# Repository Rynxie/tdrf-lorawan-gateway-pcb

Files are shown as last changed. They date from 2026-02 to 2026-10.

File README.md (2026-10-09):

# Open-Source Linux-Based LoRaWAN Gateway

A custom-designed, open-source **LoRaWAN gateway PCB** powered by the **Allwinner V3s ARM Cortex-A7 processor** and the **Semtech SX1302 LoRa concentrator**.

The gateway combines custom hardware with an embedded Linux software stack built using Buildroot, providing a flexible platform for LoRaWAN communication and IoT applications.

## Hardware Prototypes

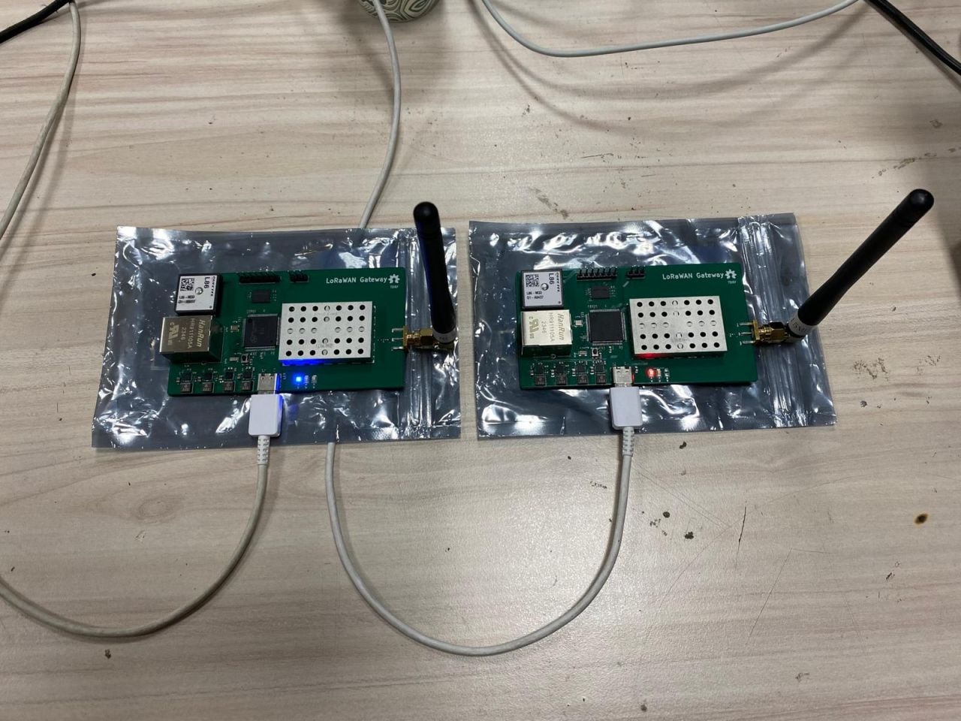
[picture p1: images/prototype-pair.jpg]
Two assembled LoRaWAN gateway prototypes


Two assembled and tested LoRaWAN gateway prototypes.

| Assembled Gateway | PCB Component Layout |
|---|---|
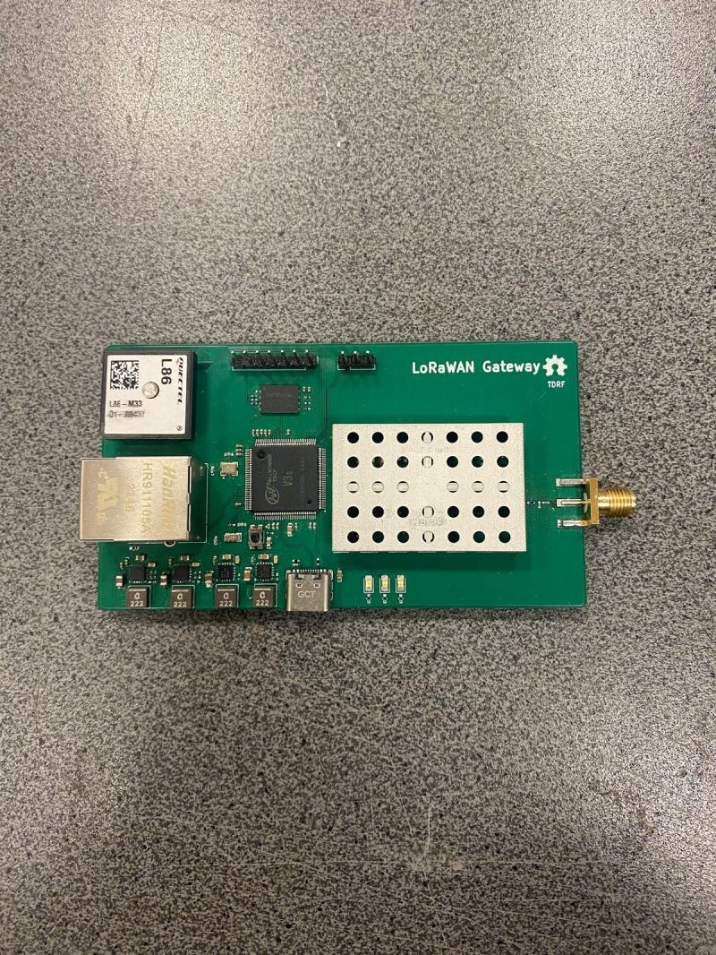
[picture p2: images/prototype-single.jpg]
Gateway prototype
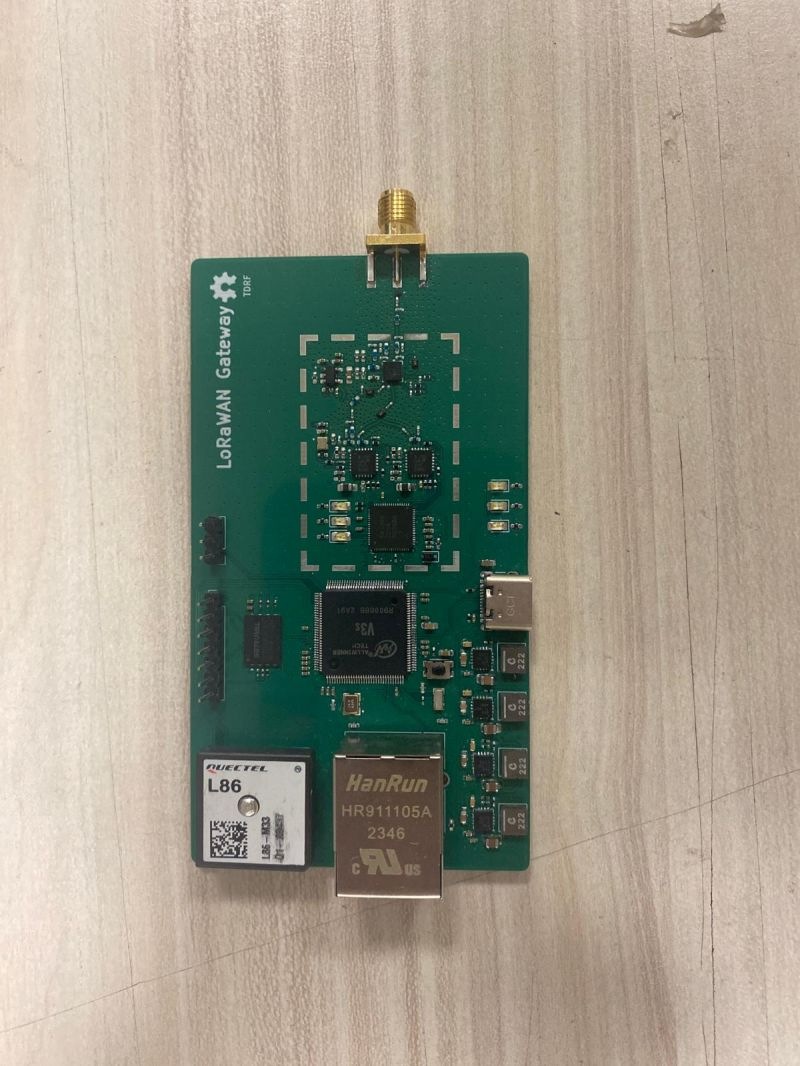
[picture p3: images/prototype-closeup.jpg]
Gateway PCB
|  |  |

## Project Overview

This project focuses on designing and developing a standalone Linux-based LoRaWAN gateway, including both custom PCB hardware and embedded Linux firmware.

The gateway was developed under the **TÜBİTAK 2209-A Undergraduate Research Projects Support Program** and subsequently integrated into the **LoRa-Based Low-Power Tracking System for Critical Cargo**, supported by the **Turkish Aerospace Industries LIFT UP Graduation Project Support Program**.

## Hardware

The hardware was designed in **KiCad**, integrating the processing unit, LoRa concentrator, RF transceivers, and peripheral interfaces on a custom PCB.

### Main Components

| Component | Description |
|---|---|
| Allwinner V3s | ARM Cortex-A7 MPU with integrated 64 MB DDR2 RAM |
| Semtech SX1302 | LoRa Core digital baseband concentrator |
| Semtech SX1250 | LoRa RF transceivers |
| Ethernet | Wired network connectivity |
| Quectel L86 | GNSS module |
| USB Type-C | USB interface |
| Custom PCB | Integrated gateway hardware platform |

## Embedded Linux Software

The gateway runs a customized embedded Linux distribution generated using **Buildroot**.

The software environment includes:

- **Linux Kernel:** Customized for the Allwinner V3s hardware platform
- **BusyBox:** Lightweight userspace utilities
- **Semtech UDP Packet Forwarder:** Forwarding LoRa packets to a network server
- **ChirpStack:** LoRaWAN Network Server integration

### System Architecture

```text
        LoRaWAN End Devices
                 |
                 | LoRa RF
                 v
       +-------------------+
       | Semtech SX1250    |
       | RF Transceivers   |
       +---------+---------+
                 |
                 v
       +-------------------+
       | Semtech SX1302    |
       | LoRa Concentrator |
       +---------+---------+
                 |
                 | SPI
                 v
       +-------------------+
       | Allwinner V3s     |
       | Embedded Linux    |
       | Buildroot         |
       | Packet Forwarder  |
       +---------+---------+
                 |
                 | Ethernet
                 v
       +-------------------+
       | ChirpStack        |
       | LoRaWAN Network   |
       | Server            |
       +-------------------+
```

## Testing and Validation

Two final hardware prototypes were manufactured, assembled, and tested.

The gateway was integrated into a LoRa-based low-power tracking system for critical cargo, providing a practical environment for evaluating the custom hardware and embedded Linux software.

We reached up to **1 km** distance in a urban area and looking for ways to increase the range

## Repository Contents

This repository focuses on the **hardware design** of the LoRaWAN gateway.

It contains the KiCad project and associated hardware design resources, including:

- PCB schematic
- PCB layout
- Component symbols and footprints
- Manufacturing and production files

## Project Team

- **Tunahan Kaya** — Embedded Linux and software development
- **Dilara Tatar** — Hardware development
- **Dr. Yalçın Albayrak** — Academic advisor

## Acknowledgments

This project was supported by the **TÜBİTAK 2209-A Undergraduate Research Projects Support Program**.

The gateway was also integrated and tested within a project supported by the **TUSAŞ LIFT UP Graduation Project Support Program**.

Special thanks to the project team and our academic advisor for their contributions and support throughout the development process.

## References

- [GitHub Repository](https://github.com/Rynxie/tdrf-lorawan-gateway-pcb)
- [Original LinkedIn Post](https://lnkd.in/p/d-5i6TTB)

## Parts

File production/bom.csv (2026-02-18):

Designator | Footprint | Quantity | Value | LCSC Part #
C1, C10, C104, C105, C107, C109, C110, C112, C113, C114, C14, C15, C16, C17, C2, C21, C22, C23, C24, C25, C26, C27, C28, C29, C3, C30, C32, C34, C35, C37, C4, C40, C41, C42, C44, C45, C46, C5, C6, C7, C8, C9 | 0201 | 42 | 100nF
C100, C38, C39 | 0201 | 3 | 10pF
C101 | 0201 | 1 | 1.3pF
C102, C98 | 0402 | 2 | 27
C103, C106, C108, C111, C18, C19, C75, C82 | 0402 | 8 | 1uF
C11, C12 | 0402 | 2 | 470nF
C115, C31, C33, C61, C62, C71, C72 | 0402 | 7 | 100nF
C116, C117, C88 | 0201 | 3 | 100n
C13, C20, C36, C43, C47, C59, C60, C69, C70 | 0603 | 9 | 10uF
C48 | 0402 | 1 | 47nF
C49 | 0201 | 1 | 47pF
C50 | 0603 | 1 | 2.2u
C51, C78, C80 | 0201 | 3 | 3.3pF
C52 | 0201 | 1 | 5.6pF
C53, C54, C56, C57 | 0201 | 4 | 3.6pF
C55 | 0201 | 1 | 39pF
C58 | 0201 | 1 | 2.2pF
C63, C64, C73, C74 | 0402 | 4 | 3.3nF
C65, C66, C76, C85, C86, C87 | 0201 | 6 | 56pF
C67, C68, C81, C83 | 0805 | 4 | 22uF
C77 | 0201 | 1 | 2.7pF
C79 | 0201 | 1 | 1.5pF
C84 | 0603 | 1 | 1u
C89 | 0603 | 1 | 4.7uF
C90 | 0402 | 1 | 10nF
C91, C95 | 0402 | 2 | 18
C92 | 0402 | 1 | 1nF
C93, C96 | 0402 | 2 | 100n
C94, C97 | 0402 | 2 | 100pF
C99 | 0201 | 1 | DNP
D1, D2, D3, D4, D5, D6 | 0805 | 6 | LED
D7 | D_SOD-323F | 1 | BAT54J
FB1 | 0402 | 1 | BLM15PG100SN1D
FL1, FL2, FL3 | B39871B4377P810 | 3 | B39871B4377P810
IC1, IC2 | QFN50P400X400X100-25N-D | 2 | SX1250IMLTRT
IC4 | QFN35P700X700X80-69N-D | 1 | SX1302IMLTRT
J1 | TE_CONSMA020.062-G | 1 | Conn_Coaxial
J2 | PinHeader_1x03_P2.54mm_Vertical | 1 | Conn_01x03_Pin
J3 | RJ45_Hanrun_HR911105A_Horizontal | 1 | RJ45_Hanrun_HR911105A_Horizontal
J5 | USB_C_Receptacle_GCT_USB4105-xx-A_16P_TopMnt_Horizontal | 1 | USB_C_Receptacle_USB2.0_16P
J6 | PinHeader_1x07_P2.54mm_Vertical | 1 | Conn_01x07_Pin
L1, L2, R13 | 0402 | 3 | NC
L10, L11, L13, L14 | L_Coilcraft_XAL4020-XXX | 4 | 2.2uH
L12, L15 | 0402 | 2 | 5.6nH
L16 | 0402 | 1 | 1.2nH
L17 | 1206 | 1 | 600Z
L18 | 0402 | 1 | 6.8nH
L19 | 0402 | 1 | 3nH
L20 | 0402 | 1 | 7.5nH
L3, L4 | 0805 | 2 | 15uH
L5 | 0402 | 1 | 47nH
L6, L9 | 0402 | 2 | 4.7nH
L7, L8 | 0402 | 2 | 12nH
R1, R2, R3 | 0402 | 3 | 0R
R10, R16, R9 | 0201 | 3 | 100kR
R11 | 0201 | 1 | 75kR
R12 | 0201 | 1 | 150kR
R14 | 0402 | 1 | 100kR
R15 | 0201 | 1 | 100k
R17 | 0201 | 1 | 80.6kR
R18 | 0201 | 1 | 220kR
R19, R20, R21 | 0201 | 3 | 1kR
R22 | 0201 | 1 | 47k
R23, R24 | 0201 | 2 | 2k
R25, R26, R27, R28, R32, R35, R36, R38 | 0402 | 8 | 1k
R29 | 0201 | 1 | 10M
R30, R31, R33, R34 | 0201 | 4 | 50
R37, R39, R62, R63, R64 | 0201 | 5 | 10K
R4, R5 | 0201 | 2 | 220R
R40 | 0402 | 1 | 10R
R41, R42, R44 | 0201 | 3 | 47kR
R43 | 0201 | 1 | 100R
R45, R46 | 0201 | 2 | 5.1kR
R47, R48, R49, R50, R51, R52, R53, R54, R55, R56, R57, R58 | 0201 | 12 | 0R
R59, R60 | 0201 | 2 | 4.7kR
R6 | 0201 | 1 | 240
R61 | 0201 | 1 | 22R
R7, R8 | 0201 | 2 | 12k
SW1 | KMR7_CNK | 1 | KMR731NG LFS
U1 | QFP40P1600X1600X160-129N | 1 | AllwinnerV3S
U10 | shield | 1 | BMI-S-205-C
U11 | SDTRUVAL_SDG02GWSIGA-CSNP2 | 1 | SDG02GWSIGA-CSNP2
U2 | XCVR_L86M33 | 1 | L86M33
U3 | VQFN-16-1EP_3x3mm_P0.5mm_EP1.68x1.68mm_ThermalVias | 1 | TPS62132
U4, U7 | VQFN-16-1EP_3x3mm_P0.5mm_EP1.68x1.68mm_ThermalVias | 2 | TPS62130
U5 | Texas_DPY0002A_0.6x1mm_P0.65mm | 1 | ESD701DPYR
U6 | VQFN-16-1EP_3x3mm_P0.5mm_EP1.68x1.68mm_ThermalVias | 1 | TPS62131
U8 | SOT95P280X145-5N | 1 | TPS7A2033PDBVR
U9 | MCM16_3X3X0P75_SKY | 1 | SKY66420-11
Y1 | OSC_TX21-M010S-32.000-X-R | 1 | TX21-M010S-32.000-X-R
Y2 | ABS07 | 1 | ABS07-32.768KHZ-7-T
Y3 | ABM810000MHZ12D2W | 1 | ABM8-24.000MHZ-B2-T

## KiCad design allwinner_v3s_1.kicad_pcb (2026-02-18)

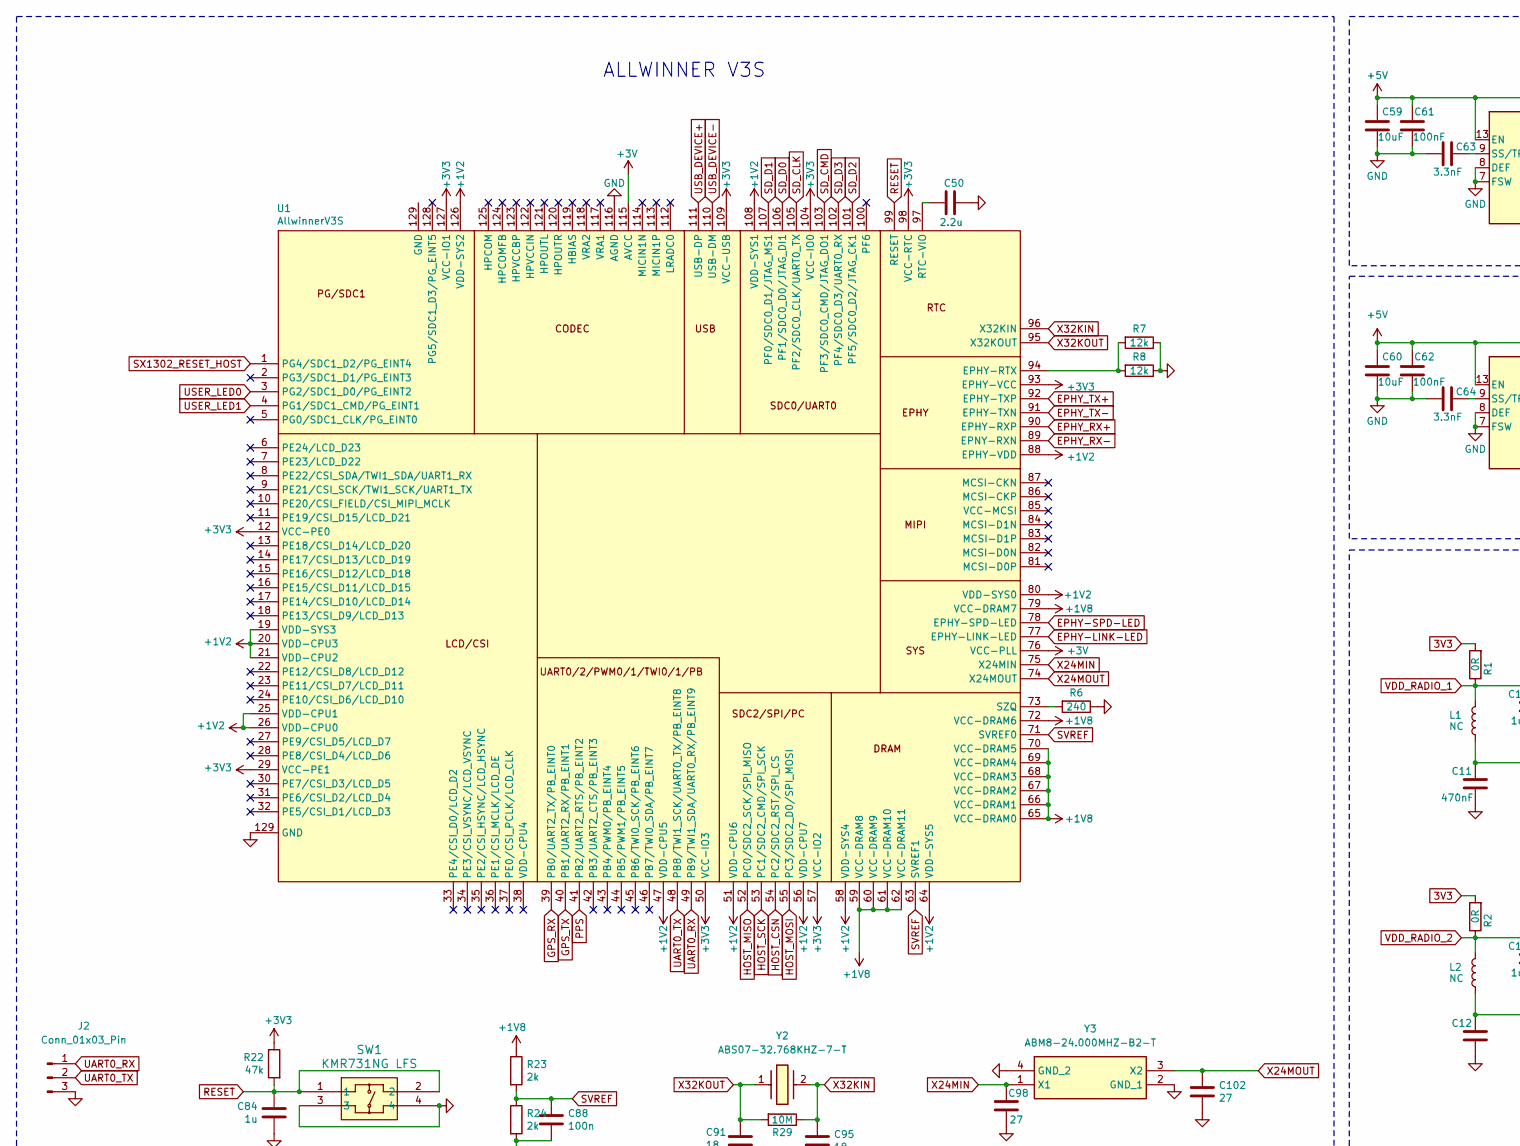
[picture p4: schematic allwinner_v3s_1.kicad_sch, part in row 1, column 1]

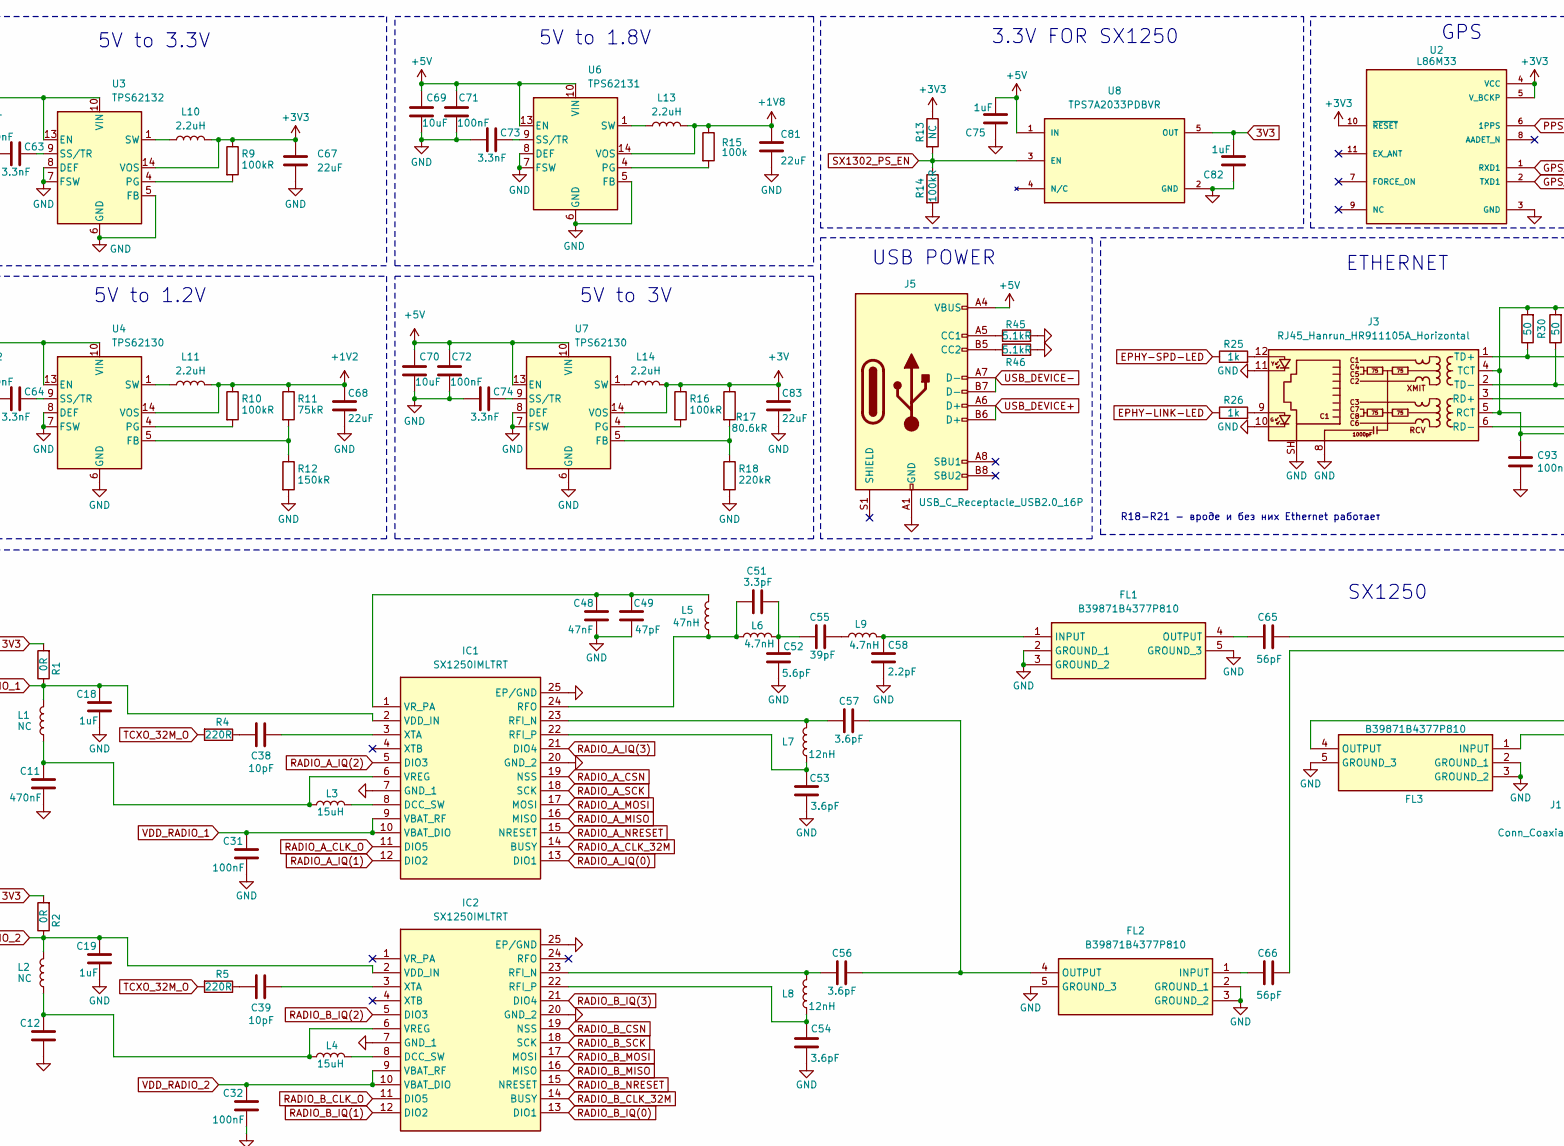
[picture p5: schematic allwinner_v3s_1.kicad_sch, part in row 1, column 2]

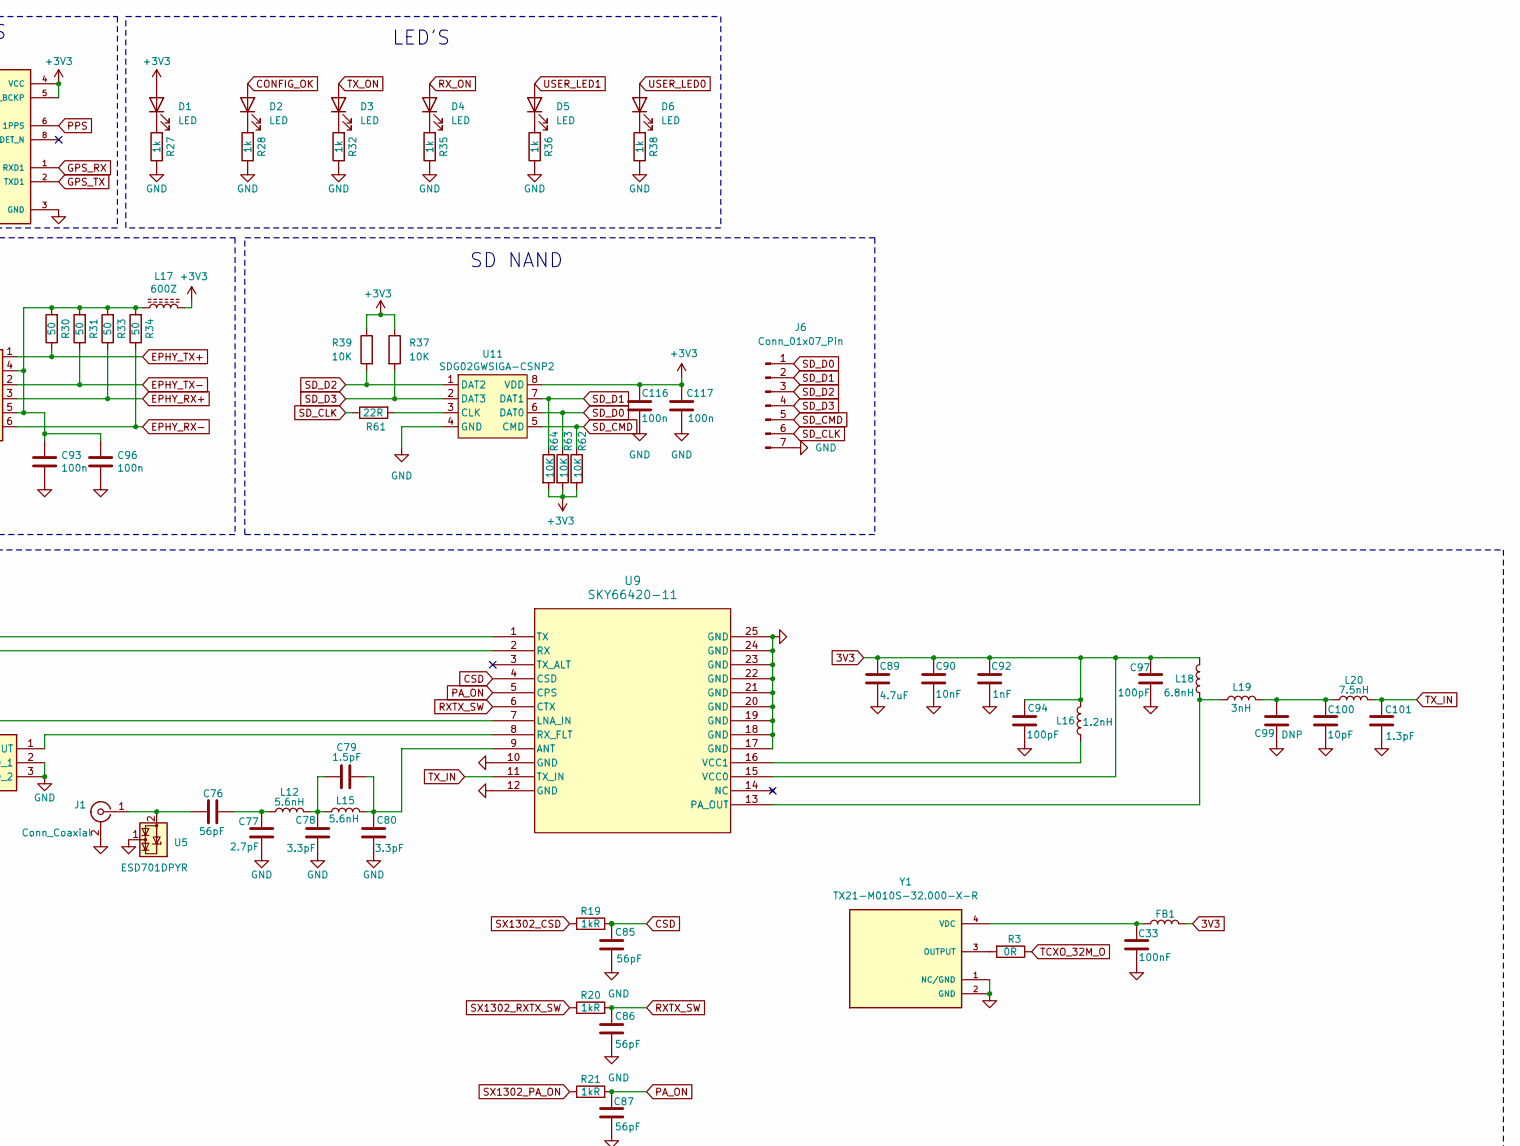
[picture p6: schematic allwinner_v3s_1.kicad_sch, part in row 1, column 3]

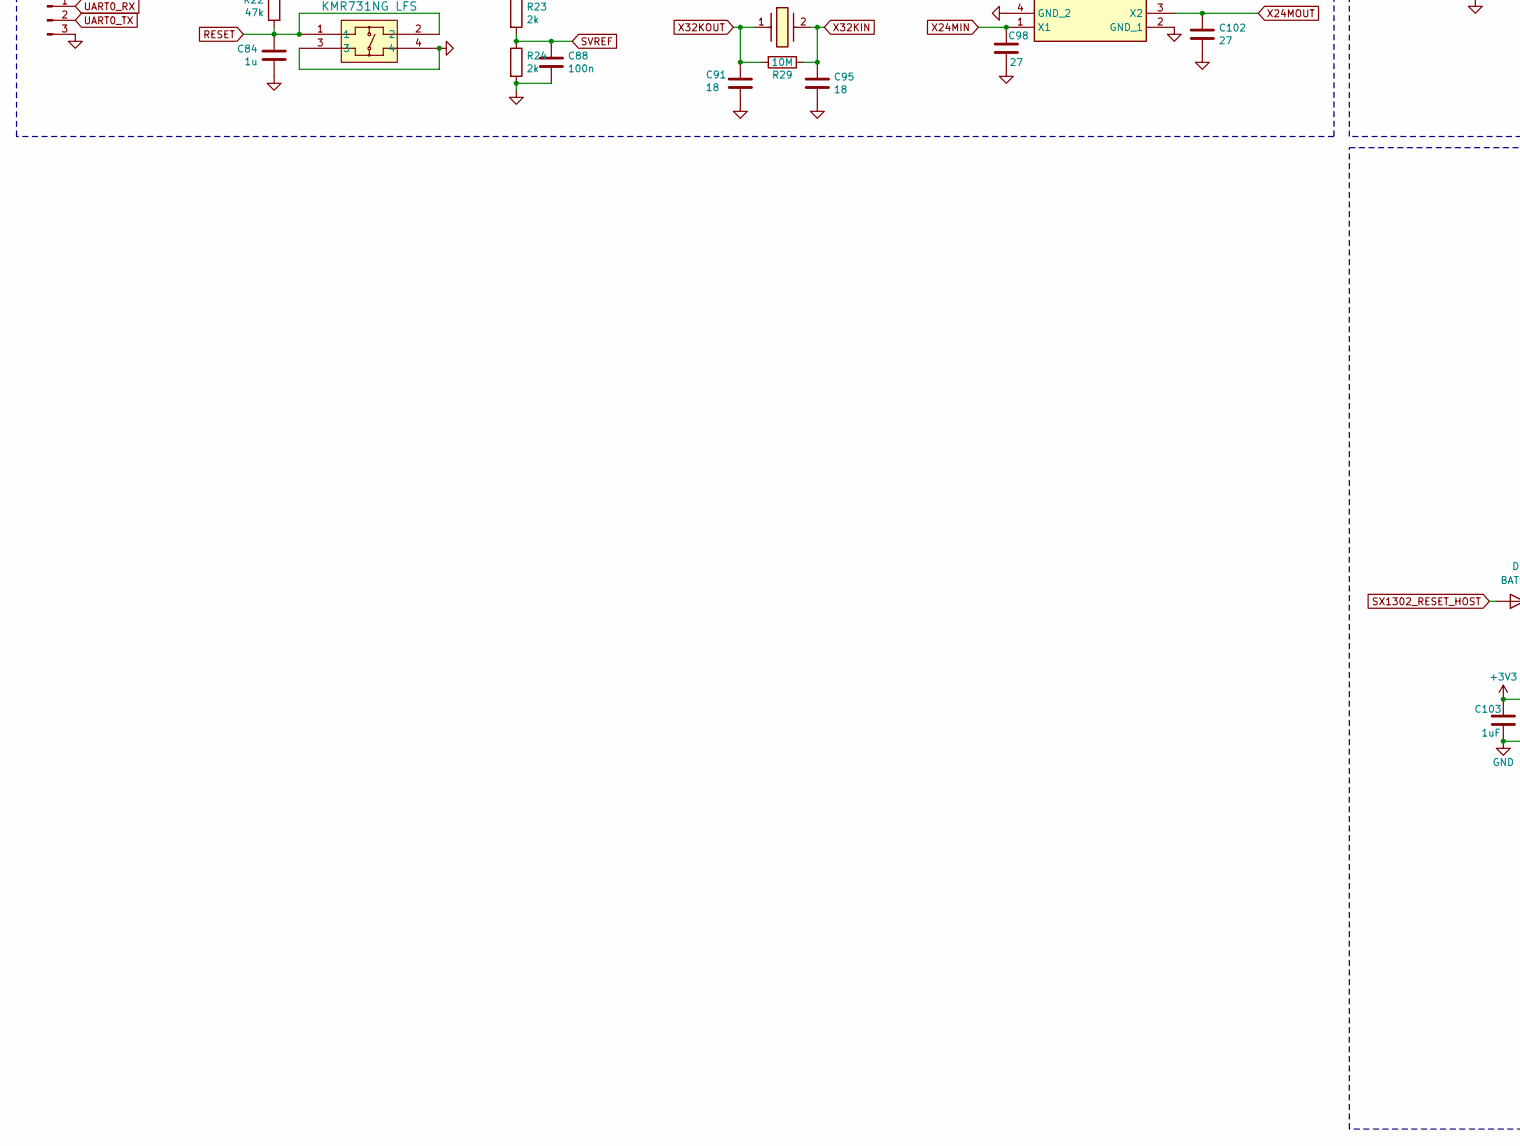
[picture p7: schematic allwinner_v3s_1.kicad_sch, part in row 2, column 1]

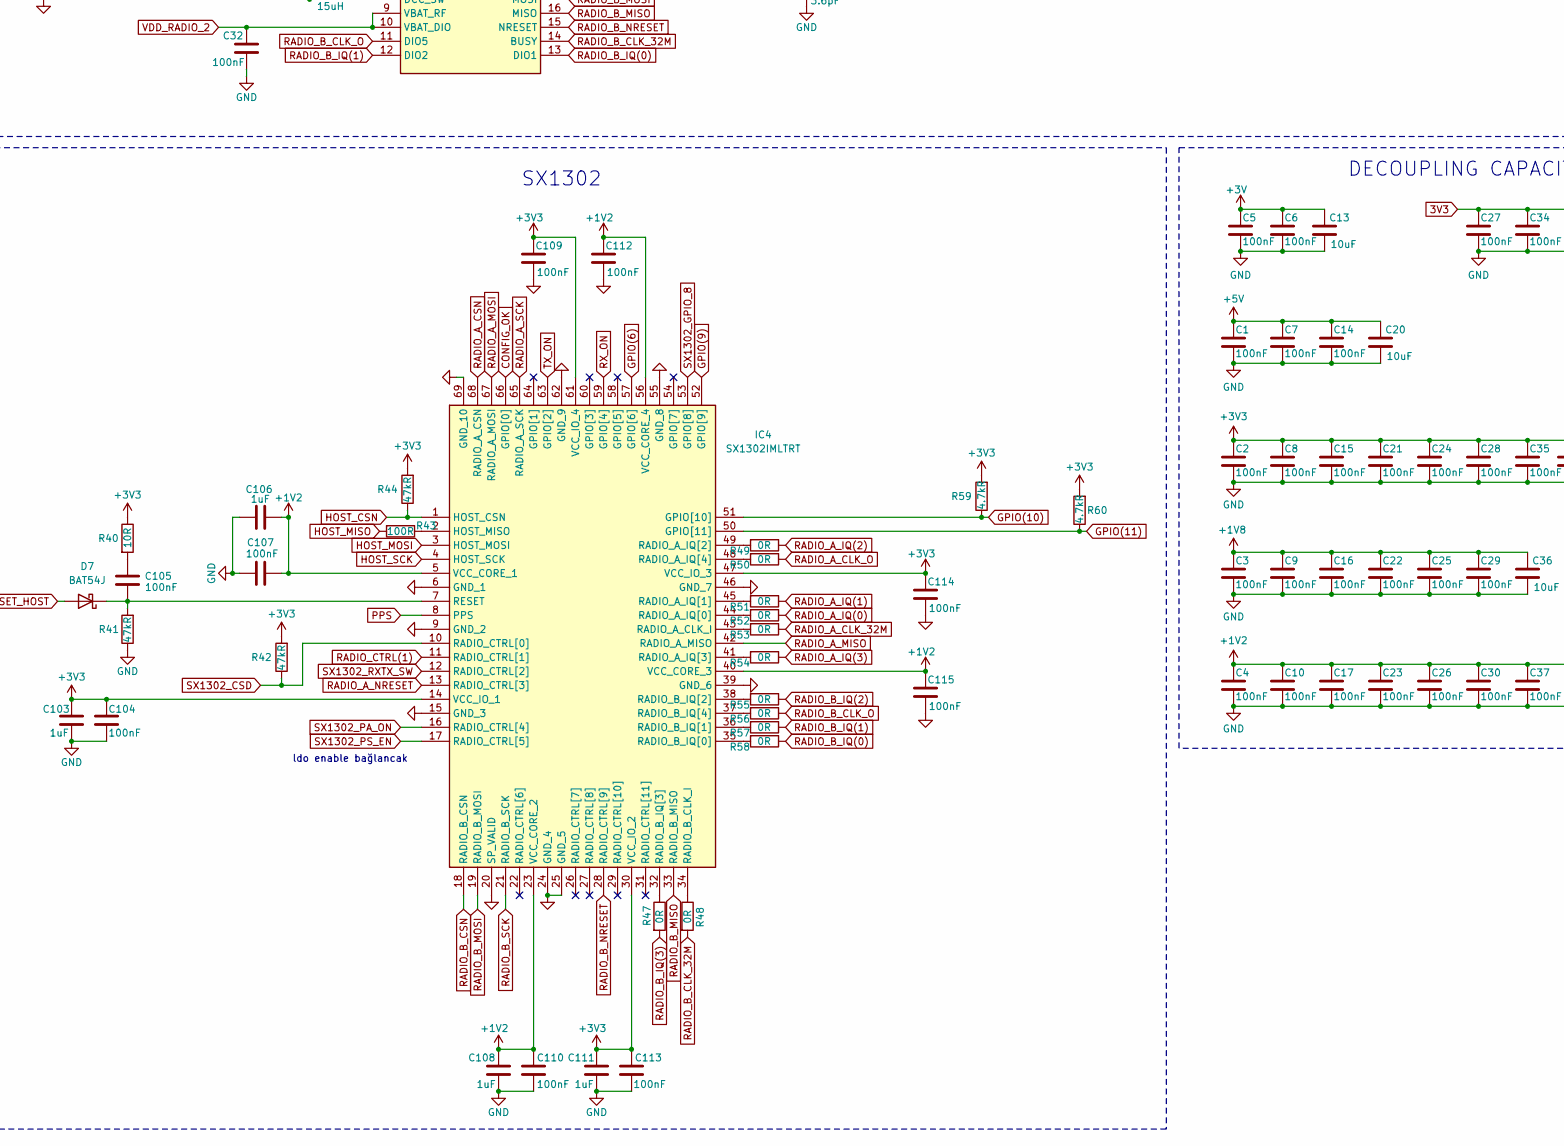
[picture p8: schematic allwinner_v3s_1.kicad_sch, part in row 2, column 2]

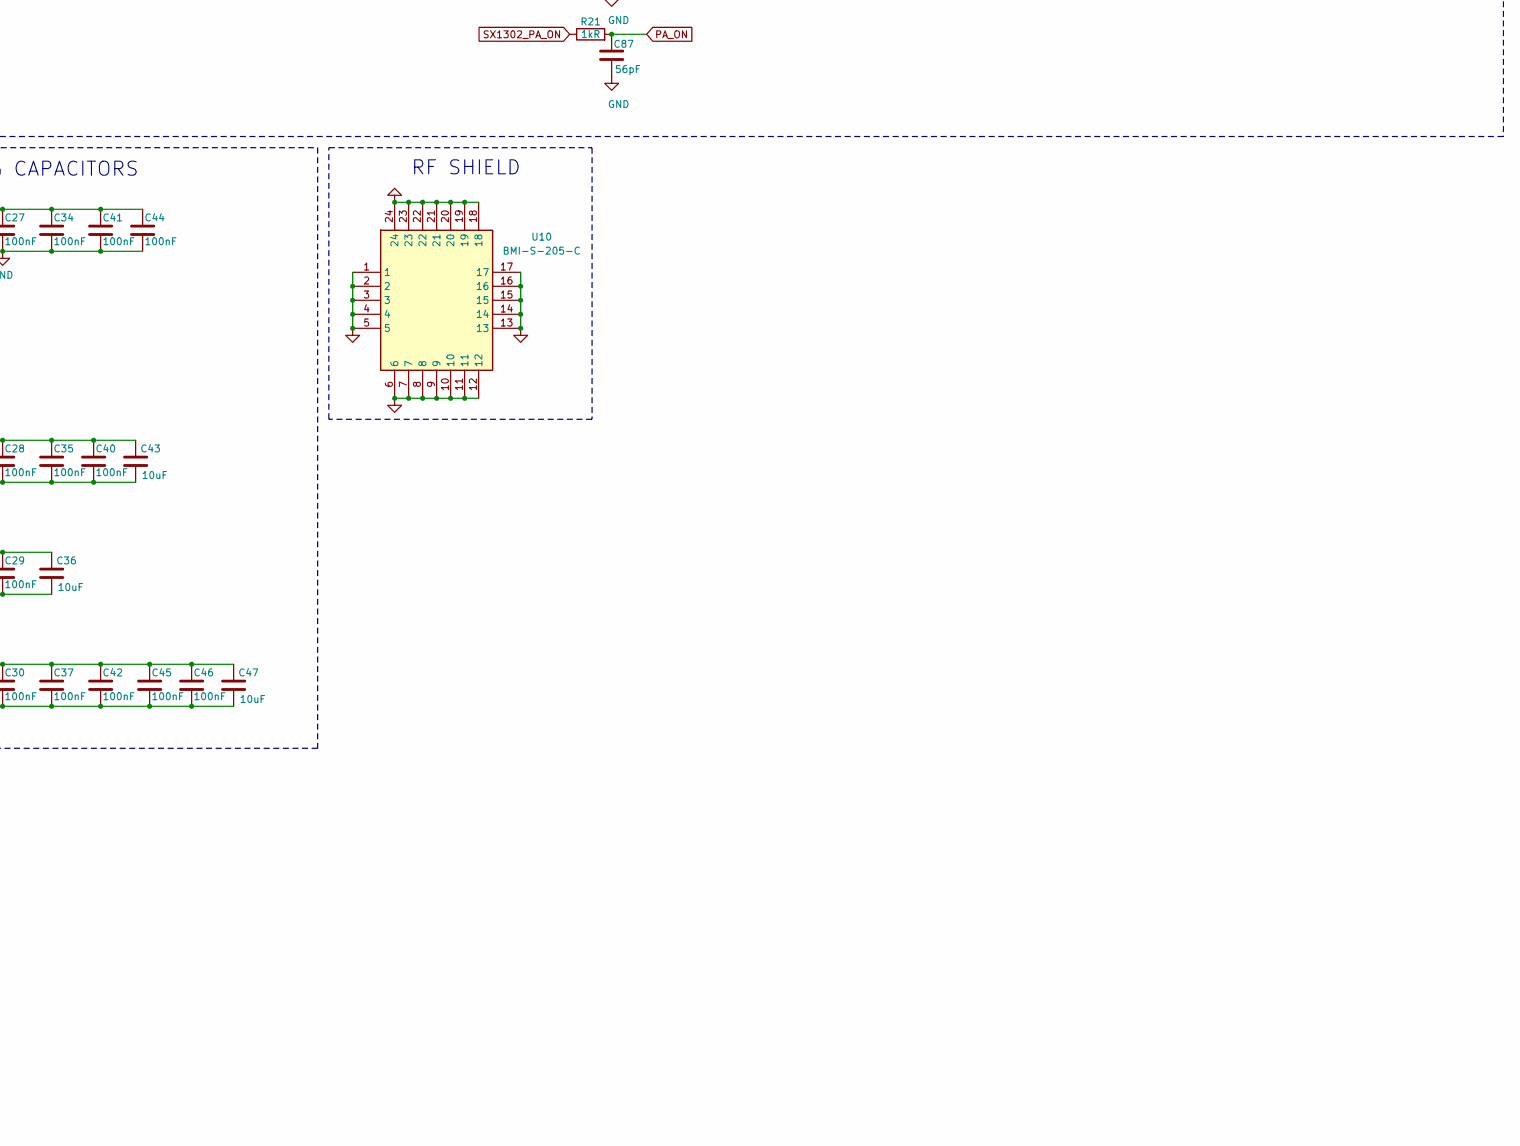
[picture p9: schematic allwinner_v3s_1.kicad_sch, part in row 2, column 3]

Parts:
C1, C2, C3, C4, C5, C6, C7, C8, C9, C10, C14, C15, C16, C17, C21, C22, C23, C24, C25, C26, C27, C28, C29, C30, C32, C34, C35, C37, C40, C41, C42, C44, C45, C46, C104, C107, C109, C110, C112, C113, C114: 100nF; C_0201_0603Metric_Pad0.64x0.40mm_HandSolder
C11, C12: 470nF; C_0402_1005Metric_Pad0.74x0.62mm_HandSolder
C13, C20, C36, C43, C47, C59, C60, C69, C70: 10uF; C_0603_1608Metric_Pad1.08x0.95mm_HandSolder
C18, C19, C75, C82, C103, C106, C108, C111: 1uF; C_0402_1005Metric_Pad0.74x0.62mm_HandSolder
C31, C33, C61, C62, C71, C72, C115: 100nF; C_0402_1005Metric_Pad0.74x0.62mm_HandSolder
C38, C39, C100: 10pF; C_0201_0603Metric_Pad0.64x0.40mm_HandSolder
C48: 47nF; C_0402_1005Metric_Pad0.74x0.62mm_HandSolder
C49: 47pF; C_0201_0603Metric_Pad0.64x0.40mm_HandSolder
C50: 2.2u; C_0603_1608Metric_Pad1.08x0.95mm_HandSolder
C51, C78, C80: 3.3pF; C_0201_0603Metric_Pad0.64x0.40mm_HandSolder
C52: 5.6pF; C_0201_0603Metric_Pad0.64x0.40mm_HandSolder
C53, C54, C56, C57: 3.6pF; C_0201_0603Metric_Pad0.64x0.40mm_HandSolder
C55: 39pF; C_0201_0603Metric_Pad0.64x0.40mm_HandSolder
C58: 2.2pF; C_0201_0603Metric_Pad0.64x0.40mm_HandSolder
C63, C64, C73, C74: 3.3nF; C_0402_1005Metric_Pad0.74x0.62mm_HandSolder
C65, C66, C76: 56pF; C_0201_0603Metric_Pad0.64x0.40mm_HandSolder
C67, C68, C81, C83: 22uF; C_0805_2012Metric_Pad1.18x1.45mm_HandSolder
C77: 2.7pF; C_0201_0603Metric_Pad0.64x0.40mm_HandSolder
C79: 1.5pF; C_0201_0603Metric_Pad0.64x0.40mm_HandSolder
C84: 1u; C_0603_1608Metric
C85, C86, C87: 56pF; C_0201_0603Metric
C88: 100n; C_0201_0603Metric_Pad0.64x0.40mm_HandSolder
C89: 4.7uF; C_0603_1608Metric_Pad1.08x0.95mm_HandSolder
C90: 10nF; C_0402_1005Metric_Pad0.74x0.62mm_HandSolder
C91, C95: 18; C_0402_1005Metric_Pad0.74x0.62mm_HandSolder
C92: 1nF; C_0402_1005Metric_Pad0.74x0.62mm_HandSolder
C93, C96: 100n; C_0402_1005Metric_Pad0.74x0.62mm_HandSolder
C94, C97: 100pF; C_0402_1005Metric_Pad0.74x0.62mm_HandSolder
C98, C102: 27; C_0402_1005Metric_Pad0.74x0.62mm_HandSolder
C99: DNP; C_0201_0603Metric_Pad0.64x0.40mm_HandSolder
C101: 1.3pF; C_0201_0603Metric_Pad0.64x0.40mm_HandSolder
C105: 100nF; R_0201_0603Metric_Pad0.64x0.40mm_HandSolder
C116, C117: 100n; C_0201_0603Metric
D1, D2, D3, D4, D5, D6: LED; LED_0805_2012Metric_Pad1.15x1.40mm_HandSolder
D7: BAT54J; D_SOD-323F
FB1: BLM15PG100SN1D; L_0402_1005Metric_Pad0.77x0.64mm_HandSolder
FL1, FL2, FL3: B39871B4377P810; Manufacturer_Part_Number B39871B4377P810; Mouser Part Number 871-B39871B4377P810
IC1, IC2: SX1250IMLTRT; QFN50P400X400X100-25N-D; Manufacturer_Part_Number SX1250IMLTRT; Mouser Part Number 947-SX1250IMLTRT
IC4: SX1302IMLTRT; QFN35P700X700X80-69N-D; Manufacturer_Part_Number SX1302IMLTRT; Mouser Part Number 947-SX1302IMLTRT
J1: Conn_Coaxial; TE_CONSMA020.062-G
J2: Conn_01x03_Pin; PinHeader_1x03_P2.54mm_Vertical
J3: RJ45_Hanrun_HR911105A_Horizontal
J5: USB_C_Receptacle_USB2.0_16P; USB_C_Receptacle_GCT_USB4105-xx-A_16P_TopMnt_Horizontal
J6: Conn_01x07_Pin; PinHeader_1x07_P2.54mm_Vertical
L1, L2: NC; L_0402_1005Metric_Pad0.77x0.64mm_HandSolder
L3, L4: 15uH; L_0805_2012Metric_Pad1.05x1.20mm_HandSolder
L5: 47nH; L_0402_1005Metric_Pad0.77x0.64mm_HandSolder
L6, L9: 4.7nH; L_0402_1005Metric_Pad0.77x0.64mm_HandSolder
L7, L8: 12nH; L_0402_1005Metric_Pad0.77x0.64mm_HandSolder
L10, L11, L13, L14: 2.2uH; L_Coilcraft_XAL4020-XXX
L12: 5.6nH; C_0402_1005Metric
L15: 5.6nH; L_0402_1005Metric_Pad0.77x0.64mm_HandSolder
L16: 1.2nH; L_0402_1005Metric_Pad0.77x0.64mm_HandSolder
L17: 600Z; L_1206_3216Metric
L18: 6.8nH; L_0402_1005Metric_Pad0.77x0.64mm_HandSolder
L19: 3nH; L_0402_1005Metric_Pad0.77x0.64mm_HandSolder
L20: 7.5nH; L_0402_1005Metric_Pad0.77x0.64mm_HandSolder
R1, R2, R3: 0R; R_0402_1005Metric_Pad0.72x0.64mm_HandSolder
R4: 220R; C_0201_0603Metric_Pad0.64x0.40mm_HandSolder
R5: 220R; R_0201_0603Metric_Pad0.64x0.40mm_HandSolder
R6: 240; R_0201_0603Metric_Pad0.64x0.40mm_HandSolder
R7, R8: 12k; R_0201_0603Metric_Pad0.64x0.40mm_HandSolder
R9, R10, R16: 100kR; R_0201_0603Metric_Pad0.64x0.40mm_HandSolder
R11: 75kR; R_0201_0603Metric_Pad0.64x0.40mm_HandSolder
R12: 150kR; R_0201_0603Metric_Pad0.64x0.40mm_HandSolder
R13: NC; R_0402_1005Metric_Pad0.72x0.64mm_HandSolder
R14: 100kR; R_0402_1005Metric_Pad0.72x0.64mm_HandSolder
R15: 100k; R_0201_0603Metric_Pad0.64x0.40mm_HandSolder
R17: 80.6kR; R_0201_0603Metric_Pad0.64x0.40mm_HandSolder
R18: 220kR; R_0201_0603Metric_Pad0.64x0.40mm_HandSolder
R19, R20, R21: 1kR; R_0201_0603Metric
R22: 47k; R_0201_0603Metric_Pad0.64x0.40mm_HandSolder
R23, R24: 2k; R_0201_0603Metric_Pad0.64x0.40mm_HandSolder
R25, R26, R27, R28, R32, R35, R36, R38: 1k; R_0402_1005Metric_Pad0.72x0.64mm_HandSolder
R29: 10M; R_0201_0603Metric_Pad0.64x0.40mm_HandSolder
R30, R31, R33, R34: 50; R_0201_0603Metric_Pad0.64x0.40mm_HandSolder
R37, R39, R62, R63, R64: 10K; R_0201_0603Metric
R40: 10R; R_0402_1005Metric_Pad0.72x0.64mm_HandSolder
R41, R42, R44: 47kR; R_0201_0603Metric_Pad0.64x0.40mm_HandSolder
R43: 100R; R_0201_0603Metric
R45, R46: 5.1kR; R_0201_0603Metric_Pad0.64x0.40mm_HandSolder
R47, R48, R49, R50, R51, R52, R53, R54, R55, R56, R57, R58: 0R; R_0201_0603Metric_Pad0.64x0.40mm_HandSolder
R59, R60: 4.7kR; R_0201_0603Metric_Pad0.64x0.40mm_HandSolder
R61: 22R; R_0201_0603Metric
SW1: KMR731NG LFS; KMR7_CNK
U1: AllwinnerV3S; QFP40P1600X1600X160-129N
U2: L86M33; XCVR_L86M33
U3: TPS62132; VQFN-16-1EP_3x3mm_P0.5mm_EP1.68x1.68mm_ThermalVias
U4, U7: TPS62130; VQFN-16-1EP_3x3mm_P0.5mm_EP1.68x1.68mm_ThermalVias
U5: ESD701DPYR; Texas_DPY0002A_0.6x1mm_P0.65mm
U6: TPS62131; VQFN-16-1EP_3x3mm_P0.5mm_EP1.68x1.68mm_ThermalVias
U8: TPS7A2033PDBVR; SOT95P280X145-5N; PARTREV H
U9: SKY66420-11; MCM16_3X3X0P75_SKY
U10: BMI-S-205-C; shield; Manufacturer_Part_Number BMI-S-205-C; Mouser Part Number 739-BMI-205-C
U11: SDG02GWSIGA-CSNP2; SDTRUVAL_SDG02GWSIGA-CSNP2
Y1: TX21-M010S-32.000-X-R; OSC_TX21-M010S-32.000-X-R; PARTREV Nov 07, 2023; DigiKey_Part_Number 3997-TX21-M010S-32.000-X-RCT-ND
Y2: ABS07-32.768KHZ-7-T; ABS07; Manufacturer_Part_Number ABS07-32.768KHZ-7-T; Mouser Part Number 815-ABS07-32.768K7T
Y3: ABM8-24.000MHZ-B2-T; ABM810000MHZ12D2W; Manufacturer_Part_Number ABM8-24.000MHZ-B2-T; Mouser Part Number 815-ABM8-24-B2-T

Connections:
3V3: C27.1, C34.1, C41.1, C44.1, C82.2, C89.2, C90.2, C92.1, C94.1, C97.1, FB1.2, L16.2, L18.2, R1.2, R2.2, U8.5 (OUT), U9.15 (VCC0)
+1V2: C4.1, C10.1, C17.1, C23.1, C26.1, C30.1, C37.1, C42.1, C45.1, C46.1, C47.1, C68.1, C106.2, C107.2, C108.2, C110.2, C112.2, C115.2, IC4.5 (VCC_CORE_1), IC4.23 (VCC_CORE_2), IC4.40 (VCC_CORE_3), IC4.56 (VCC_CORE_4), L11.2, R10.1, R11.1, U1.19 (VDD-SYS3), U1.20 (VDD-CPU3), U1.21 (VDD-CPU2), U1.25 (VDD-CPU1), U1.26 (VDD-CPU0), U1.47 (VDD-CPU5), U1.51 (VDD-CPU6), U1.56 (VDD-CPU7), U1.58 (VDD-SYS4), U1.64 (VDD-SYS5), U1.80 (VDD-SYS0), U1.88 (EPHY-VDD), U1.108 (VDD-SYS1), U1.126 (VDD-SYS2), U4.14 (VOS)
+1V8: C3.1, C9.1, C16.1, C22.1, C25.1, C29.1, C36.1, C81.1, L13.2, R15.1, R23.1, U1.59 (VCC-DRAM8), U1.60 (VCC-DRAM9), U1.61 (VCC-DRAM10), U1.62 (VCC-DRAM11), U1.65 (VCC-DRAM0), U1.66 (VCC-DRAM1), U1.67 (VCC-DRAM2), U1.68 (VCC-DRAM3), U1.69 (VCC-DRAM4), U1.70 (VCC-DRAM5), U1.72 (VCC-DRAM6), U1.79 (VCC-DRAM7), U6.14 (VOS)
+3V: C5.1, C6.1, C13.1, C83.1, L14.2, R16.1, R17.1, U1.76 (VCC-PLL), U1.115 (AVCC), U7.14 (VOS)
+3V3: C2.1, C8.1, C15.1, C21.1, C24.1, C28.1, C35.1, C40.1, C43.1, C67.1, C103.2, C104.2, C109.2, C111.2, C113.2, C114.2, C116.1, C117.1, D1.2 (A), IC4.14 (VCC_IO_1), IC4.30 (VCC_IO_2), IC4.47 (VCC_IO_3), IC4.61 (VCC_IO_4), L10.2, L17.2, R9.1, R13.1, R22.1, R37.1, R39.1, R40.1, R42.2, R44.2, R59.2, R60.2, R62.2, R63.2, R64.2, U1.12 (VCC-PE0), U1.29 (VCC-PE1), U1.50 (VCC-IO3), U1.57 (VCC-IO2), U1.93 (EPHY-VCC), U1.98 (VCC-RTC), U1.104 (VCC-IO0), U1.109 (VCC-USB), U1.127 (VCC-IO1), U2.4 (VCC), U2.5 (V_BCKP), U2.10 (~RESET), U3.14 (VOS), U11.8 (VDD)
+5V: C1.1, C7.1, C14.1, C20.1, C59.2, C60.2, C61.1, C62.1, C69.2, C70.2, C71.1, C72.1, C75.2, J5.A4 (VBUS), J5.A9 (VBUS), J5.B4 (VBUS), J5.B9 (VBUS), U3.10 (VIN), U3.11 (VIN), U3.12 (VIN), U3.13 (EN), U4.10 (VIN), U4.11 (VIN), U4.12 (VIN), U4.13 (EN), U6.10 (VIN), U6.11 (VIN), U6.12 (VIN), U6.13 (EN), U7.10 (VIN), U7.11 (VIN), U7.12 (VIN), U7.13 (EN), U8.1 (IN)
CONFIG_OK: D2.2 (A), IC4.66 (GPIO[0])
CSD: C85.1, R19.2, U9.4 (CSD)
EPHY-LINK-LED: R26.1, U1.77 (EPHY-LINK-LED)
EPHY-SPD-LED: R25.1, U1.78 (EPHY-SPD-LED)
EPHY_RX+: J3.3 (RD+), R33.1, U1.90 (EPHY-RXP)
EPHY_RX-: J3.6 (RD-), R34.1, U1.89 (EPNY-RXN)
EPHY_TX+: J3.1 (TD+), R30.1, U1.92 (EPHY-TXP)
EPHY_TX-: J3.2 (TD-), R31.1, U1.91 (EPHY-TXN)
GND: C1.2, C2.2, C3.2, C4.2, C5.2, C6.2, C7.2, C8.2, C9.2, C10.2, C11.1, C12.1, C13.2, C14.2, C15.2, C16.2, C17.2, C18.1, C19.1, C20.2, C21.2, C22.2, C23.2, C24.2, C25.2, C26.2, C27.2, C28.2, C29.2, C30.2, C31.1, C32.1, C33.1, C34.2, C35.2, C36.2, C37.2, C40.2, C41.2, C42.2, C43.2, C44.2, C45.2, C46.2, C47.2, C48.1, C49.1, C50.2, C52.1, C53.2, C54.2, C58.2, C59.1, C60.1, C61.2, C62.2, C63.1, C64.1, C67.2, C68.2, C69.1, C70.1, C71.2, C72.2, C73.1, C74.1, C75.1, C77.2, C78.1, C80.1, C81.2, C82.1, C83.2, C84.2, C85.2, C86.2, C87.2, C88.2, C89.1, C90.1, C91.2, C92.2, C93.2, C94.2, C95.2, C96.2, C97.2, C98.2, C99.2, C100.1, C101.2, C102.2, C103.1, C104.1, C106.1, C107.1, C108.1, C109.1, C110.1, C111.1, C112.1, C113.1, C114.1, C115.1, C116.2, C117.2, FL1.2 (GROUND_1), FL1.3 (GROUND_2), FL1.5 (GROUND_3), FL2.2 (GROUND_1), FL2.3 (GROUND_2), FL2.5 (GROUND_3), FL3.2 (GROUND_1), FL3.3 (GROUND_2), FL3.5 (GROUND_3), IC1.7 (GND_1), IC1.20 (GND_2), IC1.25 (EP/GND), IC2.7 (GND_1), IC2.20 (GND_2), IC2.25 (EP/GND), IC4.6 (GND_1), IC4.9 (GND_2), IC4.15 (GND_3), IC4.20 (SP_VALID), IC4.24 (GND_4), IC4.25 (GND_5), IC4.39 (GND_6), IC4.46 (GND_7), IC4.55 (GND_8), IC4.62 (GND_9), IC4.69 (GND_10), J1.2 (Ext), J2.3, J3.8, J3.10, J3.11, J3.SH, J5.A1 (GND), J5.A12 (GND), J5.B1 (GND), J5.B12 (GND), J6.7, R6.1, R7.1, R8.1, R12.2, R14.2, R18.2, R24.2, R27.1, R28.1, R32.1, R35.1, R36.1, R38.1, R41.1, R45.2, R46.2, SW1.3, SW1.4, U1.116 (AGND), U1.129 (GND), U2.3 (GND), U2.12 (GND), U3.5 (FB), U3.6 (GND), U3.7 (FSW), U3.8 (DEF), U3.15 (GND), U3.16 (GND), U3.17 (GND), U4.6 (GND), U4.7 (FSW), U4.8 (DEF), U4.15 (GND), U4.16 (GND), U4.17 (GND), U5.1 (I/O), U6.5 (FB), U6.6 (GND), U6.7 (FSW), U6.8 (DEF), U6.15 (GND), U6.16 (GND), U6.17 (GND), U7.6 (GND), U7.7 (FSW), U7.8 (DEF), U7.15 (GND), U7.16 (GND), U7.17 (GND), U8.2 (GND), U9.10 (GND), U9.12 (GND), U9.17 (GND), U9.18 (GND), U9.19 (GND), U9.20 (GND), U9.21 (GND), U9.22 (GND), U9.23 (GND), U9.24 (GND), U9.25 (GND), U10.1, U10.2, U10.3, U10.4, U10.5, U10.6, U10.7, U10.8, U10.9, U10.10, U10.11, U10.12, U10.13, U10.14, U10.15, U10.16, U10.17, U10.18, U10.19, U10.20, U10.21, U10.22, U10.23, U10.24, U11.4 (GND), Y1.1 (NC/GND), Y1.2 (GND), Y3.2 (GND_1), Y3.4 (GND_2)
GPIO(6): IC4.57 (GPIO[6])
GPIO(9): IC4.52 (GPIO[9])
GPIO(10): IC4.51 (GPIO[10]), R59.1
GPIO(11): IC4.50 (GPIO[11]), R60.1
GPS_RX: U1.39 (PB0/UART2_TX/PB_EINT0), U2.1 (RXD1)
GPS_TX: U1.40 (PB1/UART2_RX/PB_EINT1), U2.2 (TXD1)
HOST_CSN: IC4.1 (HOST_CSN), R44.1, U1.54 (PC2/SDC2_RST/SPI_CS)
HOST_MISO: R43.2, U1.52 (PC0/SDC2_SCK/SPI_MISO)
HOST_MOSI: IC4.3 (HOST_MOSI), U1.55 (PC3/SDC2_D0/SPI_MOSI)
HOST_SCK: IC4.4 (HOST_SCK), U1.53 (PC1/SDC2_CMD/SPI_SCK)
unnamed: C38.2, R4.1
unnamed: C39.2, R5.1
unnamed: C51.1, C52.2, C55.2, L6.2
unnamed: C55.1, L9.1
unnamed: C76.1, C77.1, L12.2
unnamed: C78.2, C79.1, L12.1, L15.2
unnamed: C99.1, C100.2, L19.2, L20.1
unnamed: C105.2, R40.2
unnamed: D1.1 (K), R27.2
unnamed: D2.1 (K), R28.2
unnamed: D3.1 (K), R32.2
unnamed: D4.1 (K), R35.2
unnamed: D5.1 (K), R36.2
unnamed: D6.1 (K), R38.2
unnamed: C105.1, D7.1 (K), IC4.7 (RESET), R41.2
unnamed: C58.1, FL1.1 (INPUT), L9.2
unnamed: C65.2, FL1.4 (OUTPUT)
unnamed: C66.2, FL2.1 (INPUT)
unnamed: C56.1, C57.1, FL2.4 (OUTPUT)
unnamed: FL3.1 (INPUT), U9.8 (RX_FLT)
unnamed: FL3.4 (OUTPUT), U9.7 (LNA_IN)
unnamed: IC1.8 (DCC_SW), L3.2
unnamed: C57.2, IC1.23 (RFI_N), L7.2
unnamed: C53.1, IC1.22 (RFI_P), L7.1
unnamed: C51.2, IC1.24 (RFO), L5.1, L6.1
unnamed: C11.2, IC1.6 (VREG), L1.1, L3.1
unnamed: C48.2, C49.2, IC1.1 (VR_PA), L5.2
unnamed: C38.1, IC1.3 (XTA)
unnamed: IC2.8 (DCC_SW), L4.2
unnamed: C56.2, IC2.23 (RFI_N), L8.2
unnamed: C54.1, IC2.22 (RFI_P), L8.1
unnamed: C12.2, IC2.6 (VREG), L2.1, L4.1
unnamed: C39.1, IC2.3 (XTA)
unnamed: IC4.2 (HOST_MISO), R43.1
unnamed: IC4.43 (RADIO_A_CLK_I), R53.2
unnamed: IC4.44 (RADIO_A_IQ[0]), R52.2
unnamed: IC4.45 (RADIO_A_IQ[1]), R51.2
unnamed: IC4.49 (RADIO_A_IQ[2]), R49.2
unnamed: IC4.41 (RADIO_A_IQ[3]), R54.2
unnamed: IC4.48 (RADIO_A_IQ[4]), R50.2
unnamed: IC4.34 (RADIO_B_CLK_I), R48.1
unnamed: IC4.35 (RADIO_B_IQ[0]), R58.2
unnamed: IC4.36 (RADIO_B_IQ[1]), R57.2
unnamed: IC4.38 (RADIO_B_IQ[2]), R55.2
unnamed: IC4.32 (RADIO_B_IQ[3]), R47.1
unnamed: IC4.37 (RADIO_B_IQ[4]), R56.2
unnamed: C76.2, J1.1 (In), U5.2 (GND)
unnamed: J3.9, R26.2
unnamed: J3.12, R25.2
unnamed: C93.1, C96.1, J3.4 (TCT), J3.5 (RCT), L17.1, R30.2, R31.2, R33.2, R34.2
unnamed: J5.A5 (CC1), R45.1
unnamed: J5.B5 (CC2), R46.1
unnamed: L10.1, U3.1 (SW), U3.2 (SW), U3.3 (SW)
unnamed: L11.1, U4.1 (SW), U4.2 (SW), U4.3 (SW)
unnamed: L13.1, U6.1 (SW), U6.2 (SW), U6.3 (SW)
unnamed: L14.1, U7.1 (SW), U7.2 (SW), U7.3 (SW)
unnamed: R7.2, R8.2, U1.94 (EPHY-RTX)
unnamed: C50.1, U1.97 (RTC-VIO)
unnamed: R6.2, U1.73 (SZQ)
unnamed: R9.2, U3.4 (PG)
unnamed: C63.2, U3.9 (SS/TR)
unnamed: R11.2, R12.1, U4.5 (FB)
unnamed: R10.2, U4.4 (PG)
unnamed: C64.2, U4.9 (SS/TR)
unnamed: R15.2, U6.4 (PG)
unnamed: C73.2, U6.9 (SS/TR)
unnamed: R17.2, R18.1, U7.5 (FB)
unnamed: R16.2, U7.4 (PG)
unnamed: C74.2, U7.9 (SS/TR)
unnamed: C79.2, C80.2, L15.1, U9.9 (ANT)
unnamed: L18.1, L19.1, U9.13 (PA_OUT)
unnamed: C66.1, U9.2 (RX)
unnamed: C65.1, U9.1 (TX)
unnamed: L16.1, U9.16 (VCC1)
unnamed: R61.2, U11.3 (CLK)
unnamed: R3.2, Y1.3 (OUTPUT)
unnamed: C33.2, FB1.1, Y1.4 (VDC)
PA_ON: C87.1, R21.2, U9.5 (CPS)
PPS: IC4.8 (PPS), U1.41 (PB2/UART2_RTS/PB_EINT2), U2.6 (1PPS)
RADIO_A_CLK_32M: IC1.14 (BUSY), R53.1
RADIO_A_CLK_O: IC1.11 (DIO5), R50.1
RADIO_A_CSN: IC1.19 (NSS), IC4.68 (RADIO_A_CSN)
RADIO_A_IQ(0): IC1.13 (DIO1), R52.1
RADIO_A_IQ(1): IC1.12 (DIO2), R51.1
RADIO_A_IQ(2): IC1.5 (DIO3), R49.1
RADIO_A_IQ(3): IC1.21 (DIO4), R54.1
RADIO_A_MISO: IC1.16 (MISO), IC4.42 (RADIO_A_MISO)
RADIO_A_MOSI: IC1.17 (MOSI), IC4.67 (RADIO_A_MOSI)
RADIO_A_NRESET: IC1.15 (NRESET), IC4.13 (RADIO_CTRL[3])
RADIO_A_SCK: IC1.18 (SCK), IC4.65 (RADIO_A_SCK)
RADIO_B_CLK_32M: IC2.14 (BUSY), R48.2
RADIO_B_CLK_O: IC2.11 (DIO5), R56.1
RADIO_B_CSN: IC2.19 (NSS), IC4.18 (RADIO_B_CSN)
RADIO_B_IQ(0): IC2.13 (DIO1), R58.1
RADIO_B_IQ(1): IC2.12 (DIO2), R57.1
RADIO_B_IQ(2): IC2.5 (DIO3), R55.1
RADIO_B_IQ(3): IC2.21 (DIO4), R47.2
RADIO_B_MISO: IC2.16 (MISO), IC4.33 (RADIO_B_MISO)
RADIO_B_MOSI: IC2.17 (MOSI), IC4.19 (RADIO_B_MOSI)
RADIO_B_NRESET: IC2.15 (NRESET), IC4.28 (RADIO_CTRL[9])
RADIO_B_SCK: IC2.18 (SCK), IC4.21 (RADIO_B_SCK)
RADIO_CTRL(1): IC4.11 (RADIO_CTRL[1])
RESET: C84.1, R22.2, SW1.1, SW1.2, U1.99 (RESET)
RXTX_SW: C86.1, R20.2, U9.6 (CTX)
RX_ON: D4.2 (A), IC4.59 (GPIO[4])
SD_CLK: J6.6, R61.1, U1.105 (PF2/SDC0_CLK/UART0_TX)
SD_CMD: J6.5, R62.1, U1.103 (PF3/SDC0_CMD/JTAG_DO1), U11.5 (CMD)
SD_D0: J6.1, R63.1, U1.106 (PF1/SDC0_D0/JTAG_DI1), U11.6 (DAT0)
SD_D1: J6.2, R64.1, U1.107 (PF0/SDC0_D1/JTAG_MS1), U11.7 (DAT1)
SD_D2: J6.3, R39.2, U1.101 (PF5/SDC0_D2/JTAG_CK1), U11.1 (DAT2)
SD_D3: J6.4, R37.2, U1.102 (PF4/SDC0_D3/UART0_RX), U11.2 (DAT3)
SVREF: C88.1, R23.2, R24.1, U1.63 (SVREF1), U1.71 (SVREF0)
SX1302_CSD: IC4.10 (RADIO_CTRL[0]), R19.1, R42.1
SX1302_GPIO_8: IC4.53 (GPIO[8])
SX1302_PA_ON: IC4.16 (RADIO_CTRL[4]), R21.1
SX1302_PS_EN: IC4.17 (RADIO_CTRL[5]), R13.2, R14.1, U8.3 (EN)
SX1302_RESET_HOST: D7.2 (A), U1.1 (PG4/SDC1_D2/PG_EINT4)
SX1302_RXTX_SW: IC4.12 (RADIO_CTRL[2]), R20.1
TCXO_32M_O: R3.1, R4.2, R5.2
TX_IN: C101.1, L20.2, U9.11 (TX_IN)
TX_ON: D3.2 (A), IC4.63 (GPIO[2])
UART0_RX: J2.1, U1.49 (PB9/TWI1_SDA/UART0_RX/PB_EINT9)
UART0_TX: J2.2, U1.48 (PB8/TWI1_SCK/UART0_TX/PB_EINT8)
USB_DEVICE+: J5.A6 (D+), J5.B6 (D+), U1.111 (USB-DP)
USB_DEVICE-: J5.A7 (D-), J5.B7 (D-), U1.110 (USB-DM)
USER_LED0: D6.2 (A), U1.3 (PG2/SDC1_D0/PG_EINT2)
USER_LED1: D5.2 (A), U1.4 (PG1/SDC1_CMD/PG_EINT1)
VDD_RADIO_1: C18.2, C31.2, IC1.2 (VDD_IN), IC1.9 (VBAT_RF), IC1.10 (VBAT_DIO), L1.2, R1.1
VDD_RADIO_2: C19.2, C32.2, IC2.2 (VDD_IN), IC2.9 (VBAT_RF), IC2.10 (VBAT_DIO), L2.2, R2.1
X24MIN: C98.1, U1.75 (X24MIN), Y3.1 (X1)
X24MOUT: C102.1, U1.74 (X24MOUT), Y3.3 (X2)
X32KIN: C95.1, R29.1, U1.96 (X32KIN), Y2.2
X32KOUT: C91.1, R29.2, U1.95 (X32KOUT), Y2.1

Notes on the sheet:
ldo enable bağlancak
LED'S
3.3V FOR SX1250
SX1302
5V to 1.2V
5V to 3.3V
USB POWER
RF SHIELD
ETHERNET
SX1250
5V to 3V
ALLWINNER V3S
SD NAND
R18-R21 - вроде и без них Ethernet работает
GPS
DECOUPLING CAPACITORS
5V to 1.8V

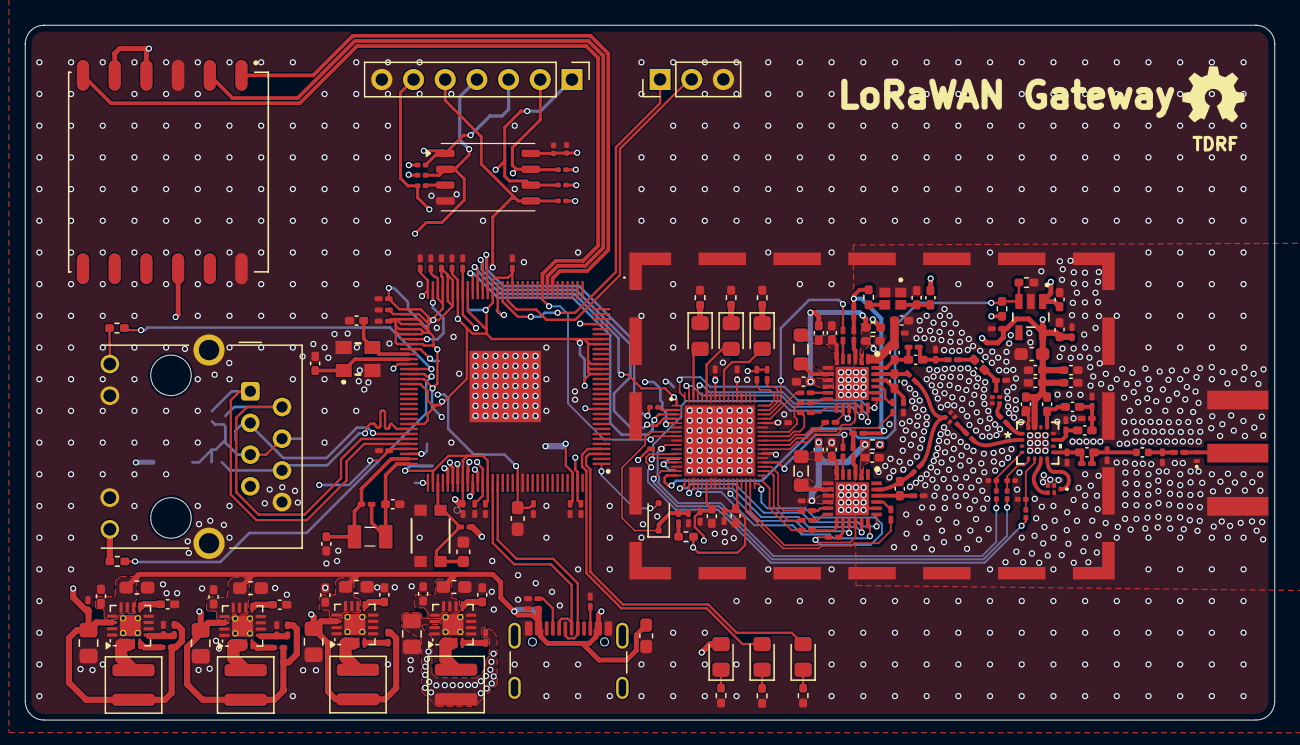
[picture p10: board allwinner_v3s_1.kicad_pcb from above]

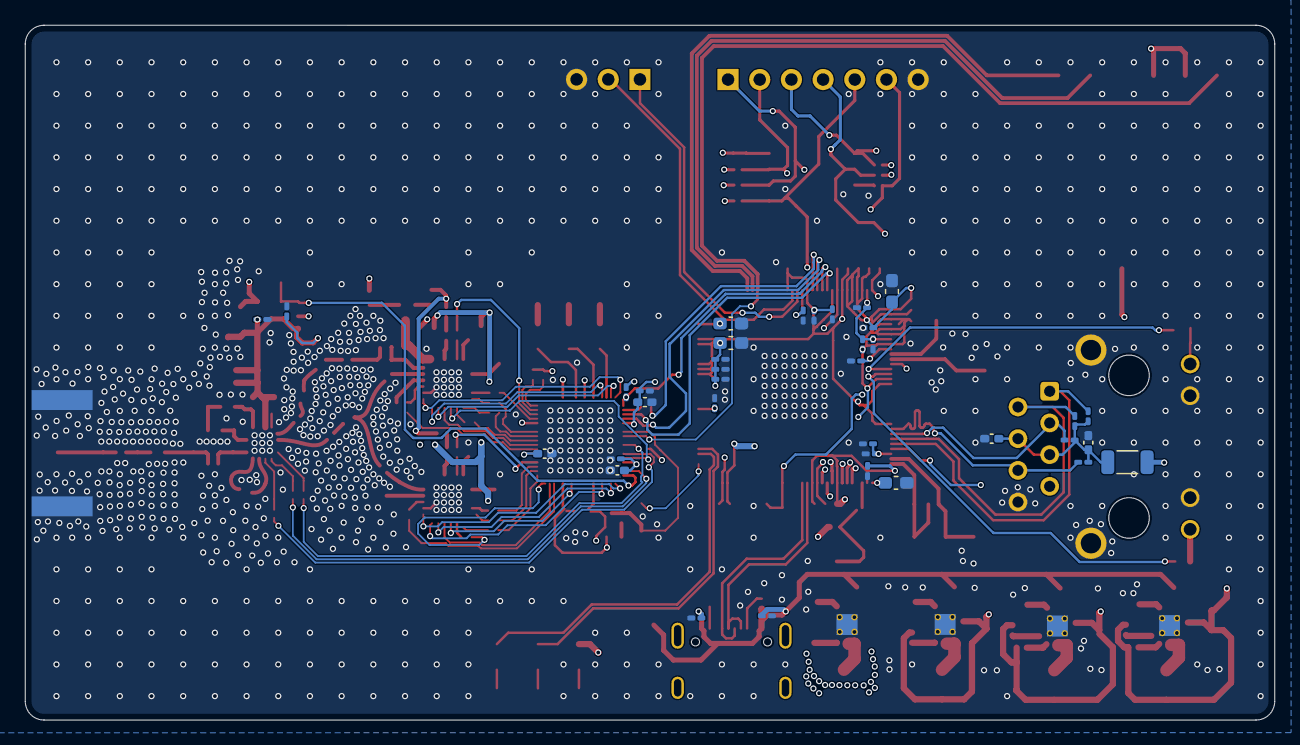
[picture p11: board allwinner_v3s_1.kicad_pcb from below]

Board: 4 copper layers, 100.2 x 55.7 mm, 235 parts (36 on the bottom side), 154 nets.

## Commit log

2026-02-18 The ___ invisible ghost gerber curve trace deleted :)
    [allwinner_v3s_1.kicad_pcb]
2026-02-18 Gerbers generated
    [allwinner_v3s_1.kicad_pcb, positions.csv]
